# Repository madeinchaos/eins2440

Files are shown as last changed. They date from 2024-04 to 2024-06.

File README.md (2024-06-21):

# EINS2440

This project provides a complete hardware and software solution based on the S3C2440 ARM9 processor.  
It includes KiCad schematics and PCB designs, as well as U-Boot, Linux kernel, and root filesystem ports.

## Directory
- **hardware**: KiCad schematics and PCB design for the eins2440 board.
- **software**: Ported U-Boot, Linux kernel, root filesystem and others.

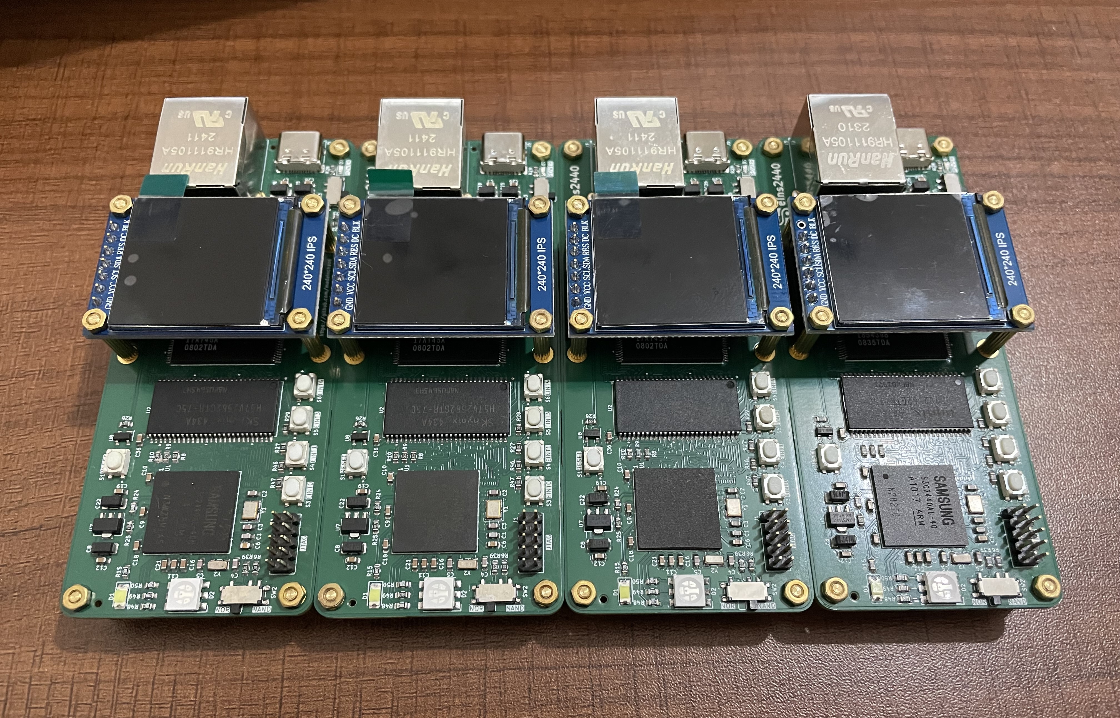
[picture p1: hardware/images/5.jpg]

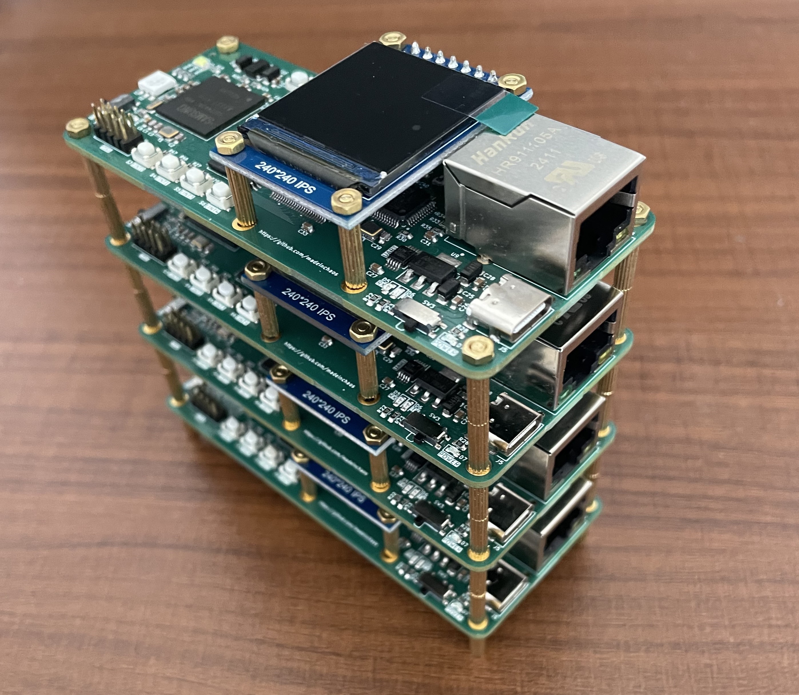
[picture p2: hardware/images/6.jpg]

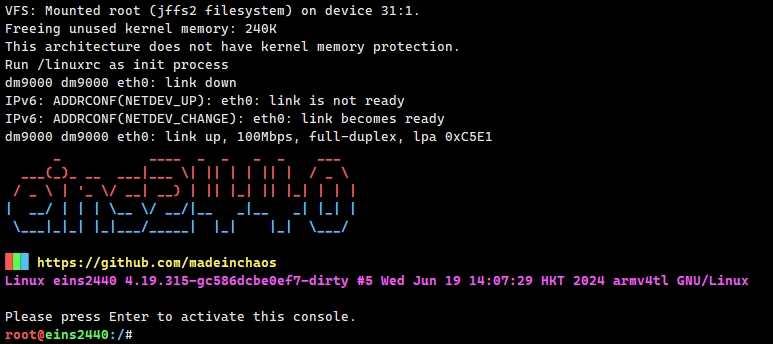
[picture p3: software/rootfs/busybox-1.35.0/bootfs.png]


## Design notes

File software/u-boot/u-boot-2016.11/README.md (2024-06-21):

# Porting u-boot-2016.11 to the board eins2440

## Setup the environment

The GCC version should be the same year as the u-boot version, otherwise some unexpected errors may occur.

The older versions of the GCC can be downloaded from [Linaro website](https://releases.linaro.org/components/toolchain/binaries/).
```
$ wget https://releases.linaro.org/components/toolchain/binaries/4.9-2016.02/arm-linux-gnueabi/gcc-linaro-4.9-2016.02-x86_64_arm-linux-gnueabi.tar.xz
$ tar xvf gcc-linaro-4.9-2016.02-x86_64_arm-linux-gnueabi.tar.xz
```

Replace $YOUR_PATH with your own directory
```
$ export PATH=$PATH:$YOUR_PATH/gcc-linaro-4.9-2016.02-x86_64_arm-linux-gnueabi/bin
$ export LD_LIBRARY_PATH=$LD_LIBRARY_PATH:$YOUR_PATH/gcc-linaro-4.9-2016.02-x86_64_arm-linux-gnueabi/lib
```

### Check the version
```
$ arm-linux-gnueabi-gcc --version

arm-linux-gnueabi-gcc (Linaro GCC 4.9-2016.02) 4.9.4 20151028 (prerelease)
Copyright (C) 2015 Free Software Foundation, Inc.
This is free software; see the source for copying conditions.  There is NO
warranty; not even for MERCHANTABILITY or FITNESS FOR A PARTICULAR PURPOSE.
```

## Get the u-boot source code
```
$ wget https://ftp.denx.de/pub/u-boot/u-boot-2016.11.tar.bz2
$ tar xvf u-boot-2016.11.tar.bz2
```

## Patch 0001-port.patch and compile
```
$ cp 0001-port.patch ./u-boot-2016.11
$ cd ./u-boot-2016.11
$ git apply 0001-port.patch

$ make eins2440_defconfig
$ make ARCH=arm CROSS_COMPILE=arm-linux-gnueabi- -j6
```

After compiling, you can download u-boot.bin to eins2440 using jlink.
Once the download is complete and reboot, you should see the following screen.
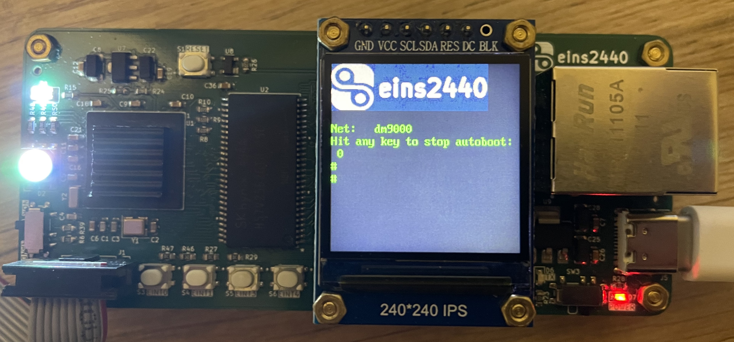
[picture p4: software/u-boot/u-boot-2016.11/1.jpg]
boot-w150


## Examples of u-boot commands

**Miscellaneous**
```
# bdinfo
arch_number = 0x000000C1
boot_params = 0x30000100
DRAM bank   = 0x00000000
-> start    = 0x30000000
-> size     = 0x04000000
eth0name    = dm9000
ethaddr     = 08:00:3e:26:0a:5b
current eth = dm9000
ip_addr     = 10.10.10.155
baudrate    = 115200 bps
TLB addr    = 0x33FF0000
relocaddr   = 0x33F1F000
reloc off   = 0x33F1F000
irq_sp      = 0x33B0EEF0
sp start    = 0x33B0EEE0
FB base     = 0x33FD3000

# version

U-Boot 2016.11 (May 19 2024 - 21:55:54 +0800)
arm-linux-gnueabi-gcc (Linaro GCC 4.9-2016.02) 4.9.4 20151028 (prerelease)
GNU ld (GNU Binutils for Ubuntu) 2.38

# bootz 30008000
# bootm 30008000
# reset
```

**Norflash**
```
# flinfo

Bank # 1: EON EN29LV160AB flash (16 x 16)  Size: 2 MB in 35 Sectors
  AMD Legacy command set, Manufacturer ID: 0x1C, Device ID: 0x2249
  Erase timeout: 30000 ms, write timeout: 100 ms

  Sector Start Addresses:
  00000000   RO   00004000   RO   00006000   RO   00008000   RO   00010000   RO 
  00020000   RO   00030000   RO   00040000   RO   00050000   RO   00060000   RO 
  00070000   RO   00080000        00090000        000A0000        000B0000      
  000C0000        000D0000        000E0000        000F0000        00100000      
  00110000        00120000        00130000        00140000        00150000      
  00160000        00170000        00180000   RO   00190000        001A0000      
  001B0000        001C0000        001D0000        001E0000        001F0000  

# erase 1a0000 1affff
# erase 1a0000 +10000
# erase 1:2-3
# protect on 1a0000 1affff
Protected 1 sectors
# cp.b 180000 1a0000 f0
Copy to Flash... Can't write to protected Flash sectors
# protect off 1a0000 1affff
```

**Nandflash**
```
# nand info

Device 0: nand0, sector size 128 KiB
  Page size       2048 b
  OOB size          64 b
  Erase size    131072 b
  subpagesize      512 b
  options     0x    1008
  bbt options 0x    8000

# nand read 30008000 200000 300000  /* 30008000(sdram addr), 200000(nand flash addr) */
# nand write 30008000 200000 300000 /* 30008000(sdram addr), 200000(nand flash addr) */
```

**Memory operation**
```
# md.b 30008000 f0
# cp.b 30000000 31000000 f0
```

**LED control**
```
# led all off
# led 0 on
# led 1 toggle
```

**LCD**
```
# lcdputs "hello world!"
```

**Network**
```
# ping 192.168.0.1
# dhcp 30008000 zImage.bin
# tftp 30008000 zImage.bin
# nfs 30008000 192.168.1.107:/home/linux/nfs/zImage
# tftpboot 30008000 192.168.1.107:/zImage
```

**Environment variable**
```
# print
# env set ipaddr 192.168.0.112
# setenv serverip 192.168.0.102
# env save
# saveenv
# setenv test delete
# setenv test 
# editenv bootcmd
edit: nand read 30008000 200000 300000;bootz 30008000 /* multiple commands */
```

**YAFFS**
```

```

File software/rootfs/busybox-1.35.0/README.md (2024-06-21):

# Build the root file system

## Build

Download the busybox from: https://www.busybox.net/downloads/  
Version: busybox-1.35.0

### Modify and Compile

TODO

## Download the root.jffs2 to the eins2440 using the TFTP
**You must download the kernel before you download the root file system.**  
**Please refer to kernel documentation README.md**
```sh
# download root.jffs2 to SDRAM address 30000000
# erase nandflash root partition
# write data from SDRAM address 30000000 to NAND flash root partition, 5M size
# reboot
tftp 30000000 root.jffs2 && nand erase.part root && nand write 30000000 root 500000 && reset
```

If the following screen is displayed after restarting, congratulations, it means that the system has successfully started.
pic-w100

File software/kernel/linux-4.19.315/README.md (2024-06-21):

# Build the kernel

## Build

Download the kernel from: https://www.kernel.org/  
Version: linux-4.19.315

### Modify and Compile

TODO

## Download the zImage to the eins2440 using the TFTP

Download TFTP tool from: [https://bitbucket.org/phjounin/tftpd64/downloads/](https://bitbucket.org/phjounin/tftpd64/downloads/)  
Version: tftpd64.464.zip

**Ensure eins2440 and TFTP server in the same local network.**

Set up the TFTP server as shown below. Current Directory where is the location of the zImage.
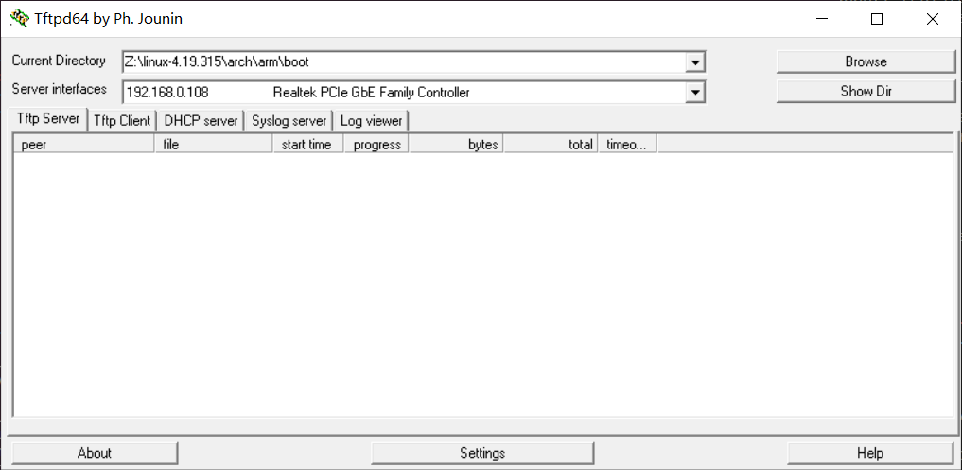
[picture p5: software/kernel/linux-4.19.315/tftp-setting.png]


Setting U-Boot environment variables:

```sh
# fill in your address
setenv gatewayip 192.168.0.1
# fill in your address
setenv netmask 255.255.255.0
# eins2440 address, fill in your address
setenv ipaddr 192.168.0.117
# address of the TFTP server, fill in your address
setenv serverip 192.168.0.108

setenv mtdids nand0=nand

# set nandflash partitions
# two partitions, a kernel partition of 5M size and the rest space for the root filesystem
setenv mtdparts 'mtdparts=nand:5m(kernel),-(root)'

setenv machid 16a

setenv bootargs 'noinitrd root=/dev/mtdblock1 rootfstype=jffs2 rw init=/linuxrc console=ttySAC0,115200'

# turn off all LEDs
# read 5M data from NAND flash address 0 to SDRAM address 30008000
# boot the zImage
setenv bootcmd 'led all off; nand read 30008000 0 500000 && bootz 30008000'

saveenv
```

Finally, download the kernel:
```sh
# download zImage to SDRAM address 30000000
# erase NAND flash kernel partition
# write data from SDRAM address 30000000 to NAND flash kernel partition, 5M size
# reboot
tftp 30000000 zImage && nand erase.part kernel && nand write 30000000 kernel 500000 && reset
```

If you see the following log in the serial console, it means the kernel has started. But there is no root file system.
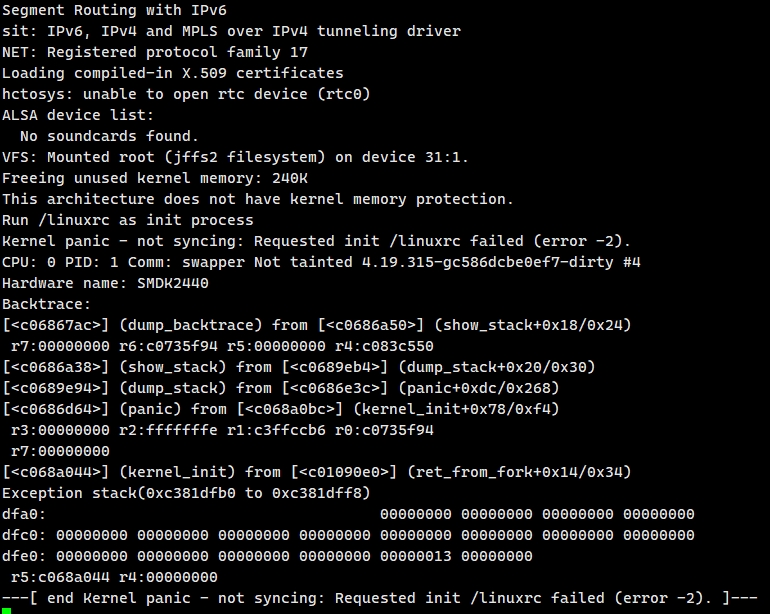
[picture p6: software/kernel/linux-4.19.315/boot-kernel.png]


Now you can proceed to create the root file system, Please refer to rootfs README.md.

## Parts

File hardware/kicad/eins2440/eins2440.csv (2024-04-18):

Source: | D:\OneDrive\tech\dev-board\eins2440\kicad\eins2440\eins2440.kicad_sch
Date: | 2024/2/23 22:14:23
Tool: | Eeschema 7.0.7
Generator: | C:\Program Files\KiCad\7.0\bin\scripting\plugins/bom_csv_grouped_by_value.py
Component Count: | 127
Collated Components:
Item | Qty | Reference(s) | Value | LibPart | Footprint | Datasheet | DNP | AVAILABILITY | Availability | Check_prices | DESCRIPTION | Description | MANUFACTURER | MAXIMUM_PACKAGE_HEIGHT | MF | MP | PACKAGE | PARTREV | PRICE | Package | Price | Purchase-URL | SNAPEDA_PN | STANDARD | SnapEDA_Link
1 | 8 | +3.3V_0, +3.3V_1, CLK_SPI0, GND_0, GND_1, MISO_SPI0, MOSI_SPI0, nSS0_SPI0 | TestPoint | Connector:TestPoint | TestPoint:TestPoint_Pad_D1.0mm | ~
2 | 1 | C1 | 2.7nF | Device:C | Capacitor_SMD:C_0603_1608Metric | ~
3 | 6 | C2, C3, C4, C5, C29, C30 | 22p | Device:C | Capacitor_SMD:C_0603_1608Metric | ~
4 | 1 | C6 | 680pF | Device:C | Capacitor_SMD:C_0603_1608Metric | ~
5 | 30 | C7, C9, C10, C11, C12, C13, C14, C15, C16, C17, C18, C19, C20, C21, C23, C24, C26, C27, C31, C32, C33, C34, C35, C36, C38, C39, C40, C41, C42, C43 | 100nF | Device:C | Capacitor_SMD:C_0603_1608Metric | ~
6 | 5 | C8, C22, C25, C28, C37 | 22uF/6.3V | Device:C_Polarized | Capacitor_SMD:C_1206_3216Metric | ~
7 | 4 | D1, D2, D3, D4 | LED | Device:LED | LED_SMD:LED_0603_1608Metric | ~
8 | 1 | D5 | TX | Device:LED | LED_SMD:LED_0603_1608Metric | ~
9 | 1 | D6 | RX | Device:LED | LED_SMD:LED_0603_1608Metric | ~
10 | 1 | D7 | POWER | Device:LED | LED_SMD:LED_0603_1608Metric | ~
11 | 4 | H1, H2, H3, H4 | MountingHole | Mechanical:MountingHole | MountingHole:MountingHole_2.2mm_M2_DIN965_Pad | ~
12 | 1 | J1 | JTAG | Connector_Generic:Conn_02x05_Odd_Even | Connector_PinHeader_1.27mm:PinHeader_2x05_P1.27mm_Vertical | ~
13 | 1 | J3 | HR911105A | HR911105A:HR911105A | lib_eins2440:HANRUN_HR911105A |  |  | Unavailable | Not in stock | https://www.snapeda.com/parts/HR911105A/HanRun/view-part/?ref=eda | DIP RJ45 Connector; |  |  |  | hanrun | HR911105A | None | A | None | None | None |  |  | Manufacturer Recommendation | https://www.snapeda.com/parts/HR911105A/HanRun/view-part/?ref=snap
14 | 1 | J4 | USB_C_Receptacle_USB2.0 | Connector:USB_C_Receptacle_USB2.0 | lib_eins2440:USB_C_Receptacle_XKB_U262-16XN-4BVC11 | https://www.usb.org/sites/default/files/documents/usb_type-c.zip
15 | 16 | R1, R4, R5, R6, R7, R13, R14, R19, R20, R40, R41, R42, R43, R44, R46, R47 | 10K | Device:R | Resistor_SMD:R_0603_1608Metric | ~
16 | 9 | R2, R3, R8, R9, R10, R11, R21, R26, R39 | 22 | Device:R | Resistor_SMD:R_0603_1608Metric | ~
17 | 2 | R12, R45 | 5.1K | Device:R | Resistor_SMD:R_0603_1608Metric | ~
18 | 9 | R15, R16, R17, R18, R22, R23, R28, R37, R38 | 1K | Device:R | Resistor_SMD:R_0603_1608Metric | ~
19 | 1 | R24 | 100_1% | Device:R | Resistor_SMD:R_0603_1608Metric | ~
20 | 1 | R25 | 4.99_1% | Device:R | Resistor_SMD:R_0603_1608Metric | ~
21 | 1 | R30 | 6.8K | Device:R | Resistor_SMD:R_0603_1608Metric | ~
22 | 2 | R31, R32 | 4.7K | Device:R | Resistor_SMD:R_0603_1608Metric | ~
23 | 4 | R33, R34, R35, R36 | 49.9 | Device:R | Resistor_SMD:R_0603_1608Metric | ~
24 | 4 | S1, S2, S3, S4 | TL3365AF180QG | TL3365AF180QG:TL3365AF180QG | lib_eins2440:SW_TL3365AF180QG |  |  |  | In Stock | https://www.snapeda.com/parts/TL3365AF180QG/E-Switch/view-part/?ref=eda |  | Tactile Switch SPST-NO Top Actuated Surface Mount | E-Switch | 2.5 mm | E-Switch | TL3365AF180QG |  | A |  | None | None | https://www.snapeda.com/api/url_track_click_mouser/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 switch | TL3365AF180QG | Manufacturer Recommendations | https://www.snapeda.com/parts/TL3365AF180QG/E-Switch/view-part/?ref=snap
25 | 1 | U1 | S3C2440AL-40 | :S3C2440AL-40_3 | lib_eins2440:S3C2440AL-40_SAM | S3C2440AL-40
26 | 2 | U2, U3 | HY57V561620CT-H | HY57V561620:HY57V561620CT-H | lib_eins2440:TSOP54_HNX | HY57V561620CT-H
27 | 1 | U4 | K9F2G08U0C-PCBO | K9F2G08U0C:K9F2G08U0C-PCBO | lib_eins2440:TSOP1-48L_SAM | K9F2G08U0C-PCBO
28 | 1 | U5 | MX29LV160DBTI-70G/TR | MX29LV160DBTI:MX29LV160DBTI-70G_TR | lib_eins2440:TSOP48L_MX29LV_MAC | MX29LV160DBTI-70G/TR
29 | 1 | U6 | CH340E | Interface_USB:CH340E | Package_SO:MSOP-10_3x3mm_P0.5mm | https://www.mpja.com/download/35227cpdata.pdf
30 | 1 | U7 | AMS1117-ADJ | Regulator_Linear:AZ1117R-ADJ | Package_TO_SOT_SMD:SOT-89-3 | https://www.diodes.com/assets/Datasheets/products_inactive_data/AZ1117.pdf
31 | 1 | U8 | MAX811LEUS-T | Power_Supervisor:MAX811LEUS-T | Package_TO_SOT_SMD:SOT-143 | https://datasheets.maximintegrated.com/en/ds/MAX811-MAX812.pdf
32 | 1 | U9 | AMS1117-3.3 | Regulator_Linear:AMS1117-3.3 | Package_TO_SOT_SMD:SOT-89-3 | http://www.advanced-monolithic.com/pdf/ds1117.pdf
33 | 1 | U10 | DM9000AEP | DM9000BEP:DM9000BEP | lib_eins2440:QFP_9000BEP_DAV | DM9000BEP
34 | 1 | Y1 | 12M | Device:Crystal_GND24 | Crystal:Crystal_SMD_3225-4Pin_3.2x2.5mm | ~
35 | 1 | Y2 | 32.768kHz | Device:Crystal | lib_eins2440:XTAL_CM7V-T1A-32.768KHZ-6PF-10PPM-TA-QC | ~
36 | 1 | Y3 | 25M | Device:Crystal_GND24 | Crystal:Crystal_SMD_3225-4Pin_3.2x2.5mm | ~

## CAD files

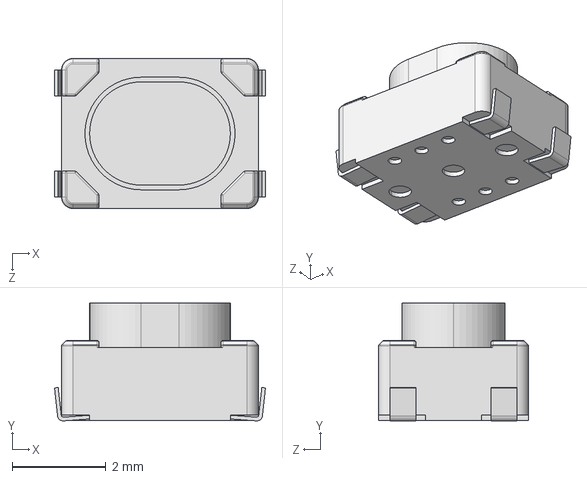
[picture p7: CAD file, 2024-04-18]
hardware/kicad/lib_eins2440/TL3365AF180QG.step
4.50 x 2.51 x 3.20 mm

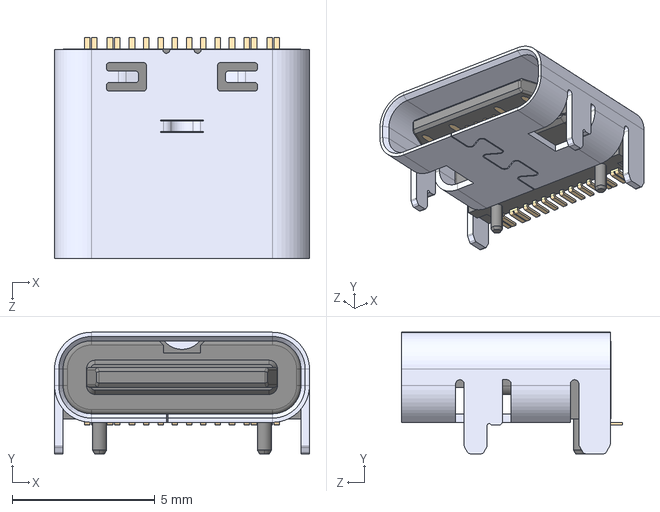
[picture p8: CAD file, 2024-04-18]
hardware/kicad/lib_eins2440/CSP-USC16-TR.step
8.94 x 4.26 x 7.75 mm

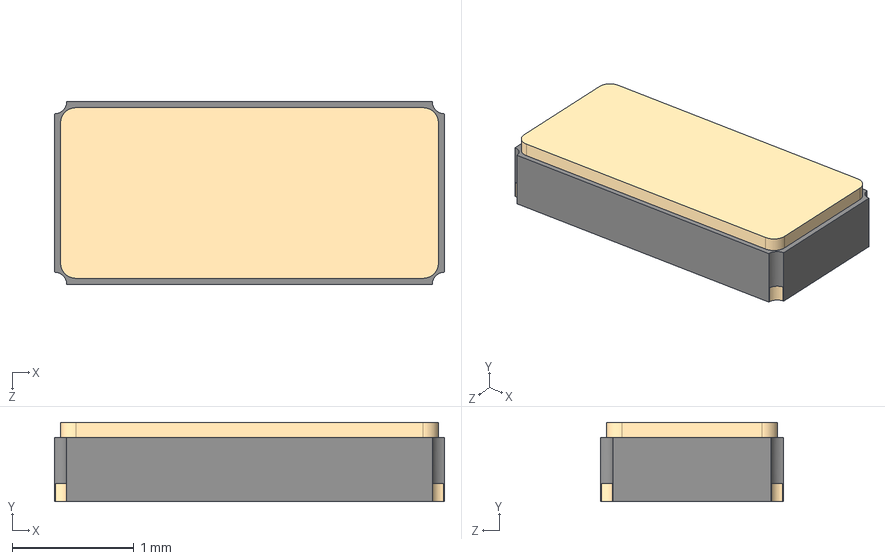
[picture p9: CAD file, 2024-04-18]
hardware/kicad/lib_eins2440/CM7V-T1A-32.768KHZ-6PF-10PPM-TA-QC.step
3.20 x 0.65 x 1.50 mm

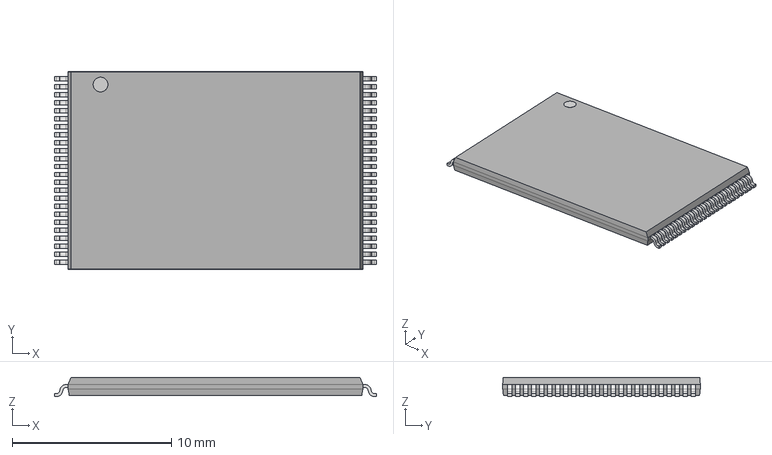
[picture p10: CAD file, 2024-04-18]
hardware/kicad/lib_eins2440/TSOP1-48L_SAM.step
20.2 x 12.4 x 1.20 mm

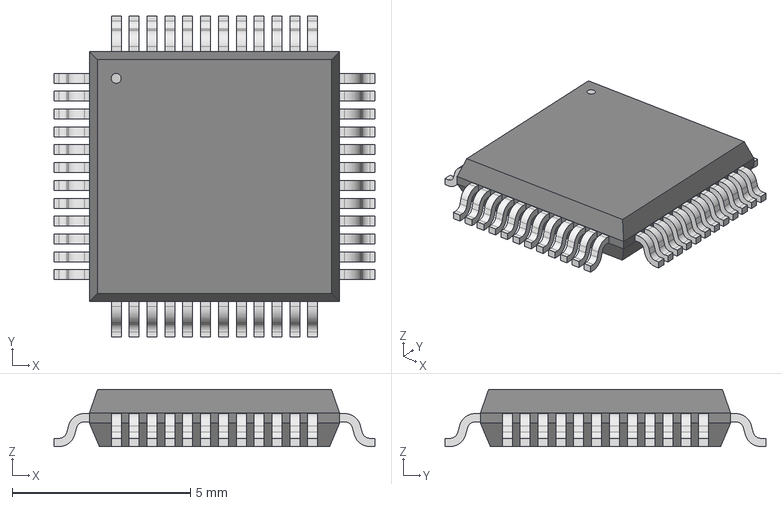
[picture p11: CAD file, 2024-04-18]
hardware/kicad/lib_eins2440/QFP_9000BEP_DAV.step
8.99 x 8.99 x 1.60 mm

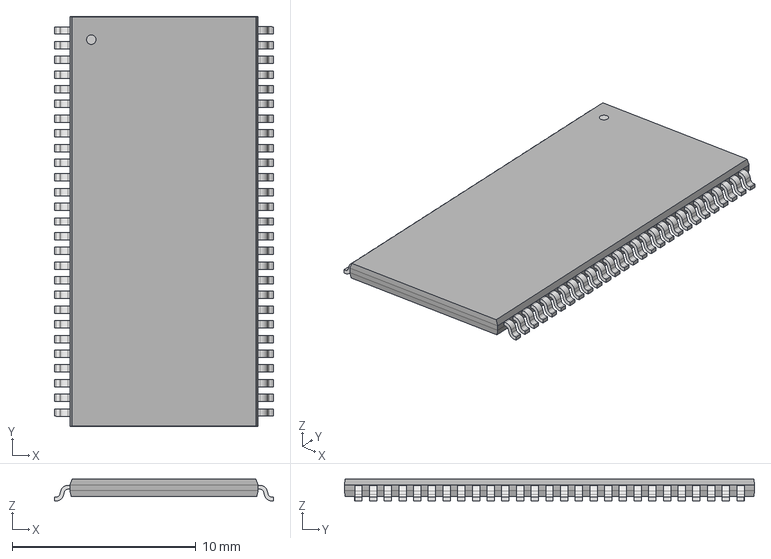
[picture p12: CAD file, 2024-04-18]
hardware/kicad/lib_eins2440/TSOP54_HNX.step
11.9 x 22.3 x 1.20 mm

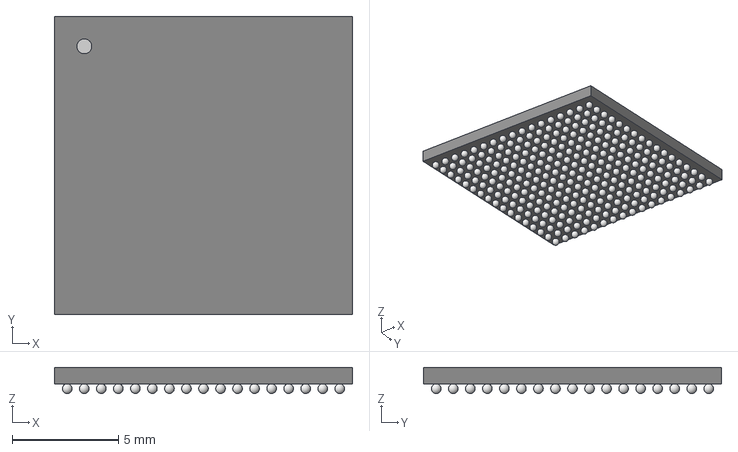
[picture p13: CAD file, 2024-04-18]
hardware/kicad/lib_eins2440/S3C2440AL-40_SAM.step
14.0 x 14.0 x 1.22 mm

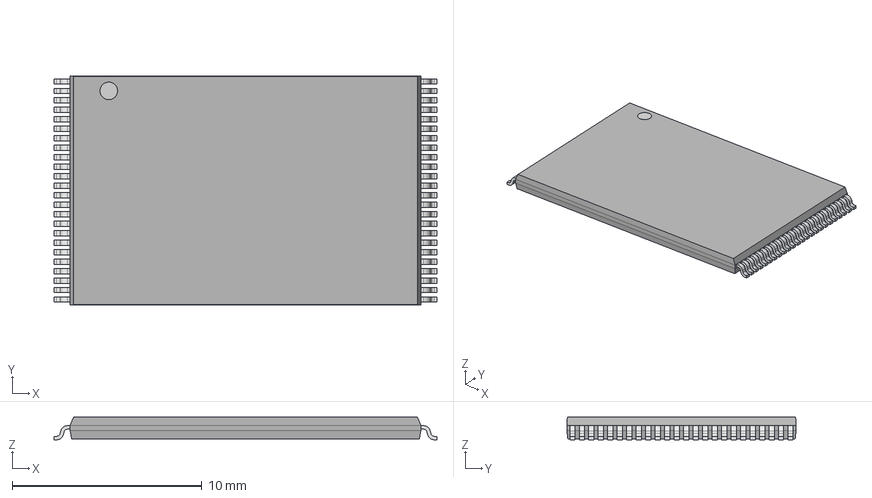
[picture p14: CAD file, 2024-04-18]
hardware/kicad/lib_eins2440/TSOP48L_MX29LV_MAC.step
20.2 x 12.1 x 1.20 mm

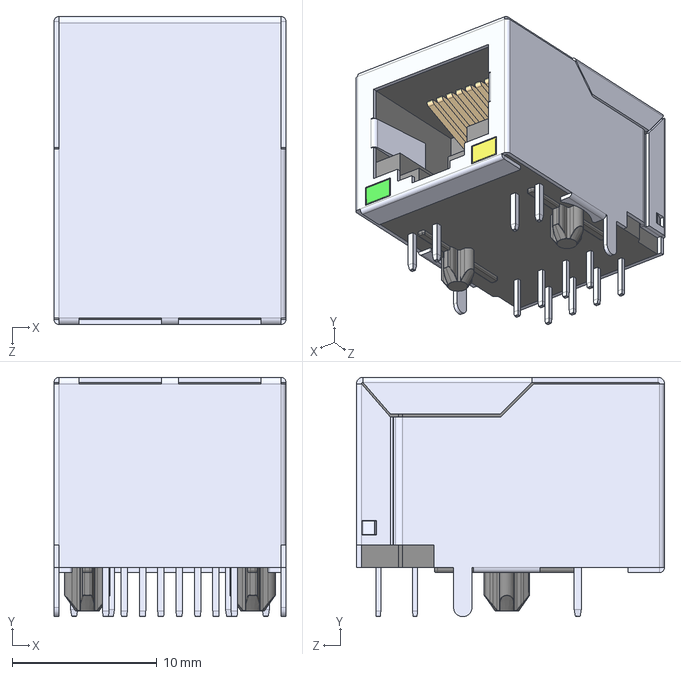
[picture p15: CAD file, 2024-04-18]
hardware/kicad/lib_eins2440/HR911105A.step
16.0 x 16.6 x 21.3 mm
